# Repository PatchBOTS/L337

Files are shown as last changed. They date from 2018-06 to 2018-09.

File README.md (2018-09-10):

L337 (https://www.youtube.com/watch?v=H4KK212-Jss)
# L3-37 Voice Assistant
### Please Read Before Downloading 3D File

## Overview

## CODE
# Amazon Voice Services Code 
My friend @henrymendez is helping me with this section.  There may be a video tutorial down the line, but at the very least Henry will be writing a super awesome script to speed up the install process.  Check back. 

# Arduino Code
Very simple code. My goal is to eliminate the Arduino altogether, but for now this operates the servo and the neopixels. 

## 3D Files
The 3D files are free for download.  There will be some updates in the near future to a couple of the main parts.  If you see a "-CS" attached to any of the files, that means it is "changing soon,"  print those last. 

I'm happy to distribute these files for free but they are not guaranteed to work.  I am very big on the "print quick and dirty and fix later" philosophy, so there may be some physical editing to the parts needed which I did not document. 

## Changes coming in V2
### Physical
At the moment L3's head lists a little to the left. This is because of my 'smart' idea to only attach via the servo spline. I'm going to modify the top of the neck piece to add in a small axle to support the load.  Also, I'm going to expand the top of the neck piece to hold some of the components (of which there will hopefully be fewer of) to take some weight off the perimeter. 
### Electrical
There is a slight hum to the amplifier. I'm going to do more research on power de-coupling and ground loops to see if I can eliminate it. I have a feeling if I get rid of hte arduino circuit that will help.  Also, I'm hoping to be able to eliminate the SBEC which I'm sure isn't helping anything. 
### Components
As mentioned above I'm going to try to eliminate the arduino and circuit board all together. This will make the entire project less complicated and less noisy in the wires. 
I used a MEGA Scale Servo because I happened to have one on hand.  L3's head came in surprisingly light, so I think if I add in the axle to support more of the weight (which will also be moved off the head) I can use a much less powerful servo which doesn't require the SBEC.  
At the moment I'm using a cheap buck converter chip to step down the voltage. I'm going to upgrade this to a board with better voltage stability to hopefully help the amplifier hum. 
### Coding
I'm going to try to figure out more about coding the pinouts on the Pi.  If I can get two pinouts with one running a software PWM, I can eliminate the Arduino altogether.  I think this is the key to V2. 

<a href="https://www.buymeacoffee.com/WjRBDa3dZ" target="_blank">Buy Me A Coffee</a>

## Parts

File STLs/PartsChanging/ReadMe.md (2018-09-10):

These parts are from a now deprecated V1.  All these parts have either changed or are no longer necessary.   Use the V2 parts for all of these components.

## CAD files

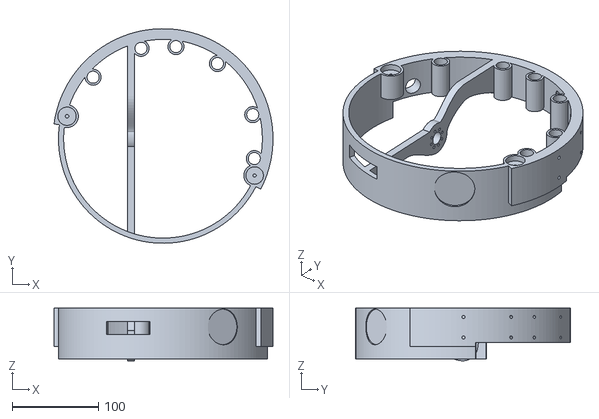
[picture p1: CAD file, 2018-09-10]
STLs/V2/HEAD_STRUCTURE_MainRing.STL
254.5 x 249.3 x 61.3

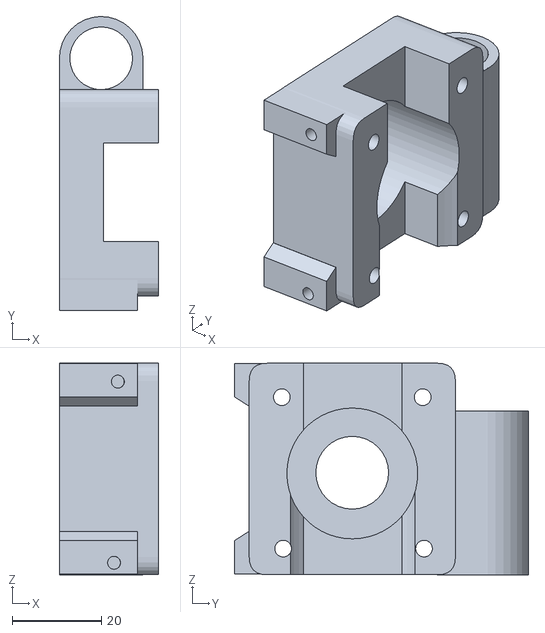
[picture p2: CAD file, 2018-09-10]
STLs/V2/HEAD_SERVOBLOCK_Main.STL
22.2 x 65.9 x 47.4

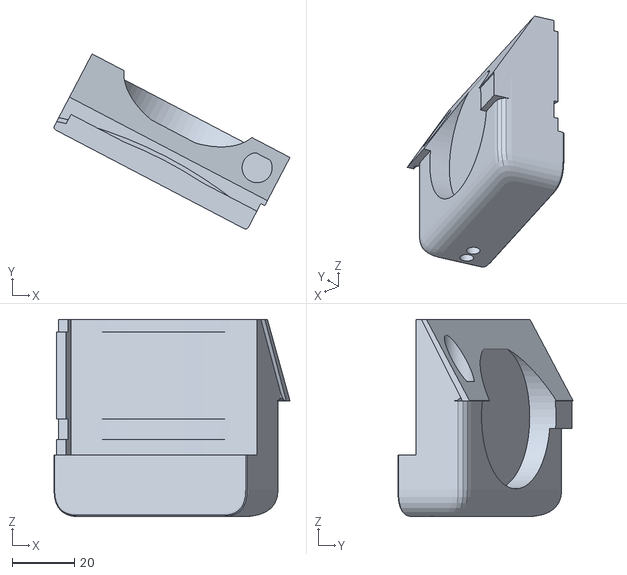
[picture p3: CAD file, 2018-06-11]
STLs/ANTENNA_Main.STL
75.9 x 56.4 x 63.5

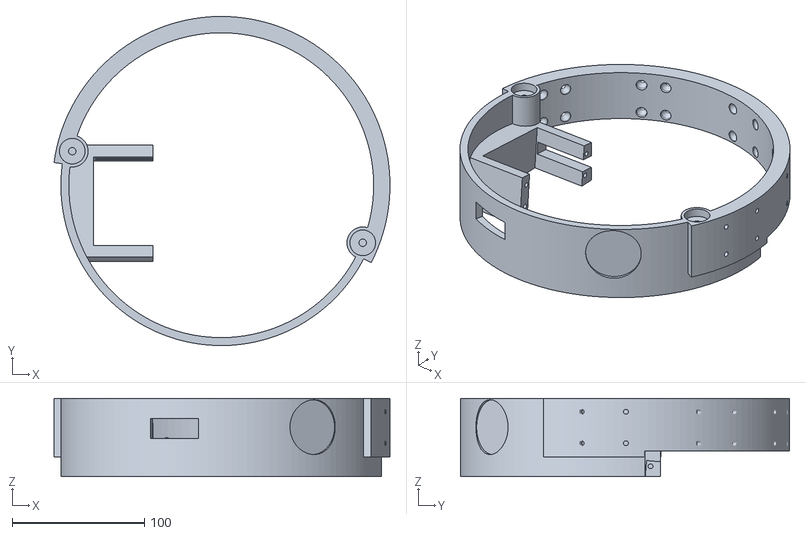
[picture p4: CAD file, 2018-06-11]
STLs/PartsChanging/HEAD_STRUCTURE_MainRing.STL
254.5 x 249.3 x 59.4

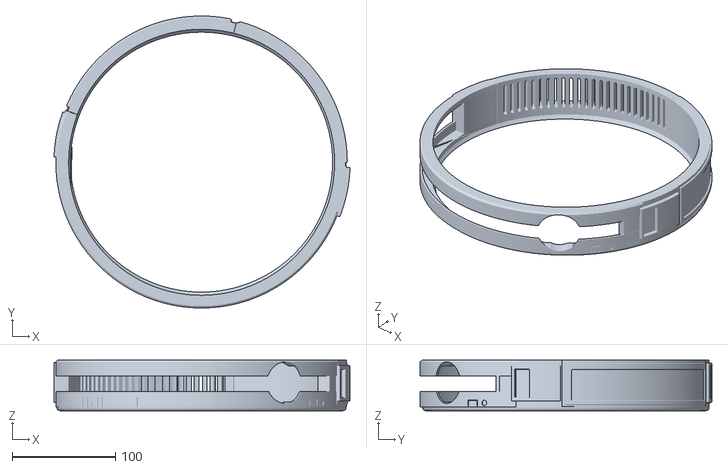
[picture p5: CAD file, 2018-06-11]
STLs/HEAD_AESTHETIC_Main.STL
287.1 x 283.2 x 49.1

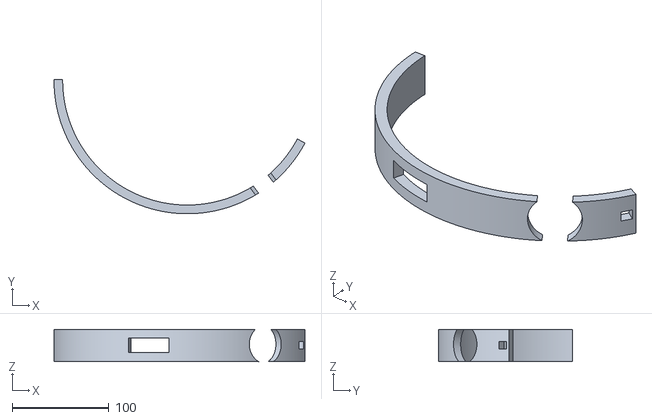
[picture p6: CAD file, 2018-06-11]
STLs/HEAD_STRUCTURE_VisorBand.STL
259.2 x 138.9 x 33.2

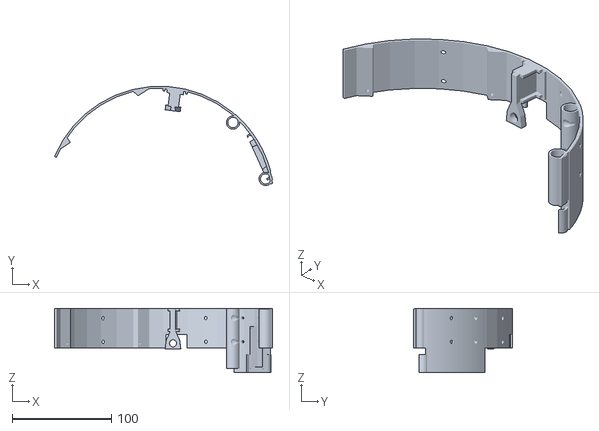
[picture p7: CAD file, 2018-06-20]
STLs/PartsChanging/HEAD_ELECTRICAL_Mount-CS.STL
219.6 x 99.8 x 64.8

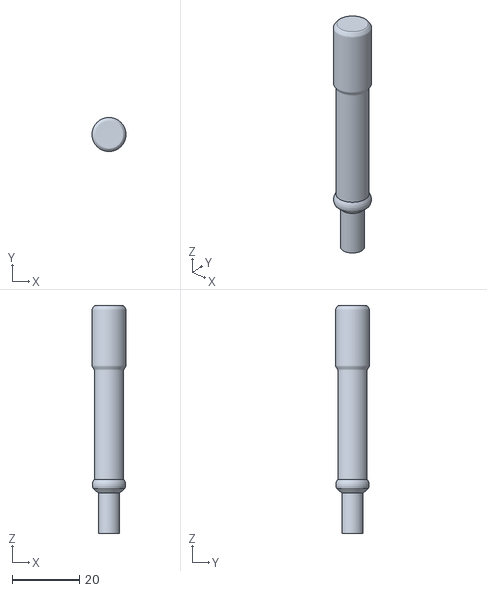
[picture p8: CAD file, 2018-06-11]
STLs/ANTENNA_Antenna.STL
10.1 x 10.1 x 68.0

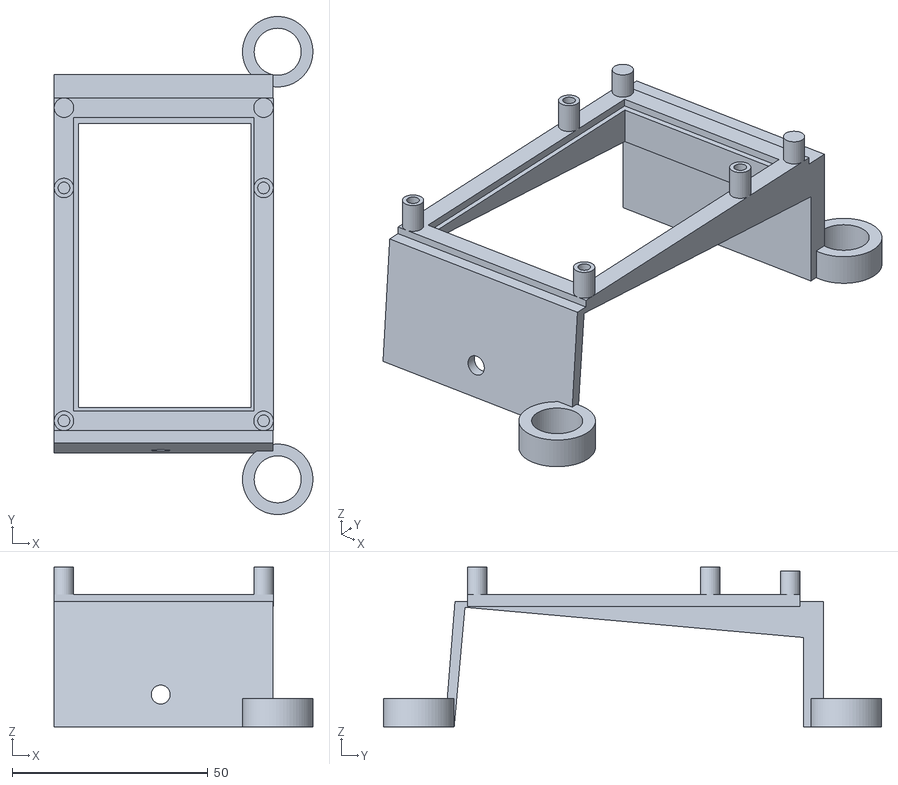
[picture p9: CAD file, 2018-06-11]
STLs/PartsChanging/HEAD_ELECTRICAL_PiHolder.STL
66.1 x 127.2 x 40.8

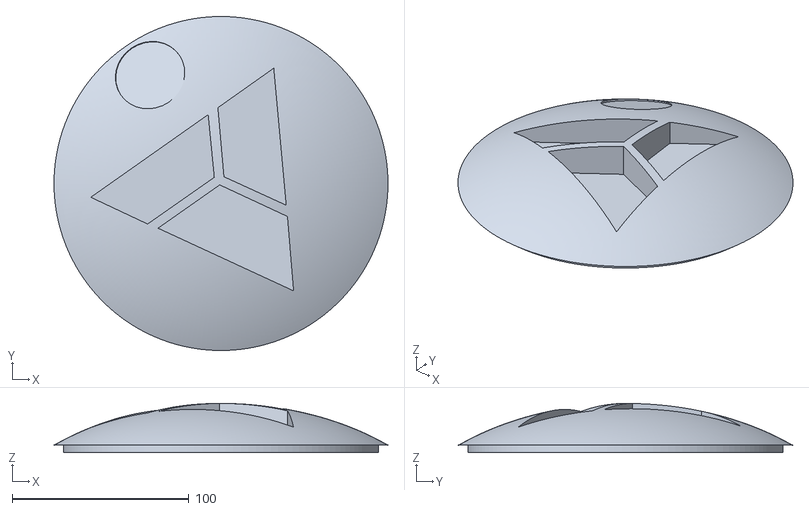
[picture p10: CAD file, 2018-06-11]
STLs/HEAD_LID_Cap.STL
189.1 x 189.1 x 27.8

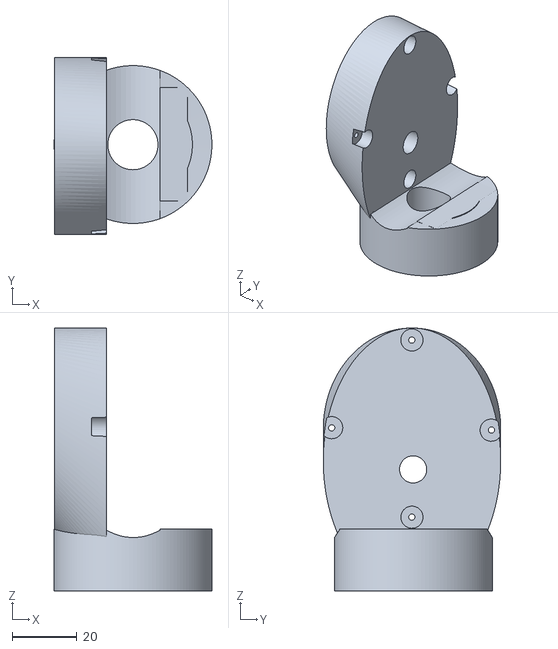
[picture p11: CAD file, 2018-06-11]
STLs/PartsChanging/BASE_NeckCap-CS.STL
48.8 x 54.9 x 81.4

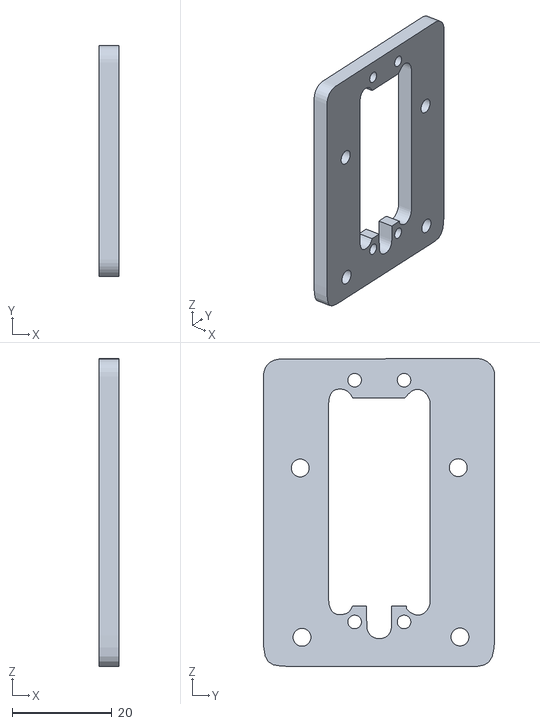
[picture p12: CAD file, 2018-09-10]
STLs/V2/HEAD_SERVOBLOCK_Plate.STL
4.00 x 46.3 x 61.6

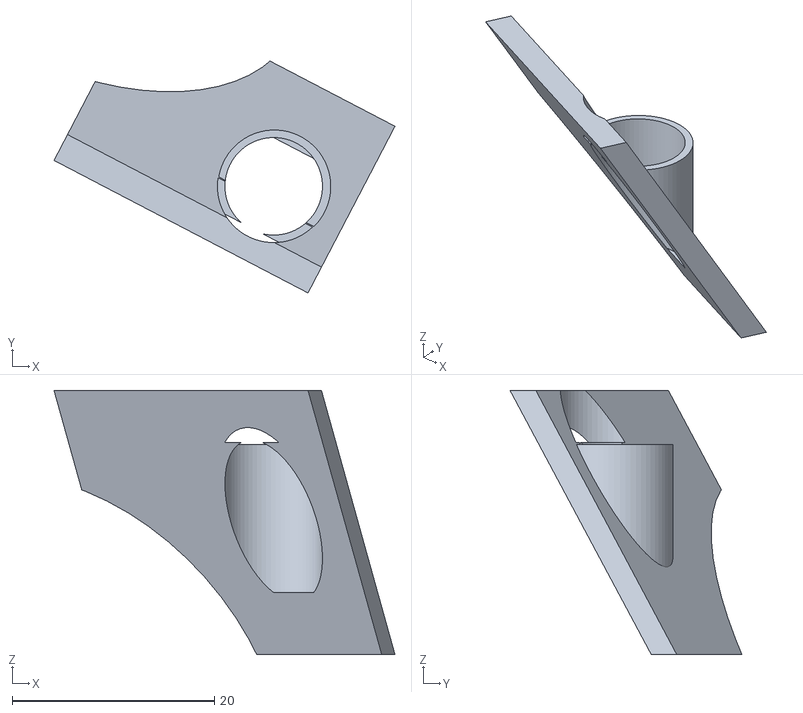
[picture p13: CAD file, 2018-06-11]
STLs/ANTENNA_SilverHolder.STL
33.8 x 23.0 x 26.1

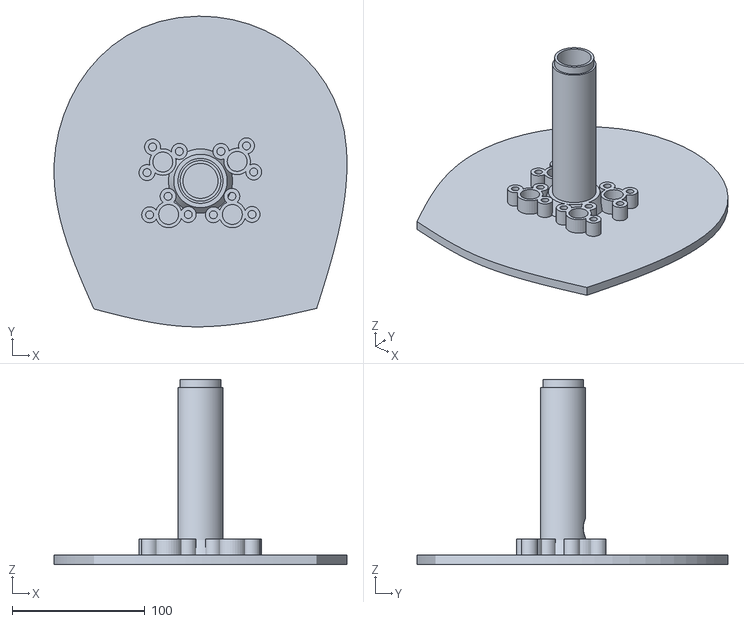
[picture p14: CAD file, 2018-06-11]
STLs/PartsChanging/BASE_BaseAndNeck-CS.STL
220.7 x 234.0 x 139.4

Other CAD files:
STLs/V2/BASE_BaseandNeck.STL
STLs/PartsChanging/HEAD_ELECTRICAL_MountCover.STL
STLs/V2/HEAD_ELECTRICAL_SpeakerMount.STL
STLs/HEAD_AESTHETIC_EarGreebly.STL
STLs/ANTENNA_Ring.STL
STLs/BASE_Collar.STL
STLs/BASE_CollarGreebly.STL
STLs/BASE_WireGrommit.STL
STLs/HEAD_AESTHETIC_Eye.STL
STLs/HEAD_AESTHETIC_EyeLid.STL
STLs/HEAD_AESTHETIC_MouthGreebly.STL
STLs/HEAD_AESTHETIC_VisorGreebly.STL
STLs/HEAD_ELECTRICAL_NeoDiffusex2.STL
STLs/HEAD_ELECTRICAL_NeoPixelHolder.STL
STLs/HEAD_LID_Base.STL
STLs/HEAD_LID_Cap_Holo.STL
STLs/HEAD_LID_Cap_T1.STL
STLs/HEAD_LID_Cap_T2.STL
STLs/HEAD_LID_Cap_T3.STL
STLs/PartsChanging/HEAD_ELECTRICAL_InternalHoop.STL
STLs/PartsChanging/HEAD_ELECTRICAL_SpeakerMount_CS.STL

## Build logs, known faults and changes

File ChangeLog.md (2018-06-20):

# Changelog
This file is to keep everyone following up to date on what is happening in between videos. 

## Alexa/Raspberry Pi Tutorial Video
This video is priority one.   @henrymendez put together a bunch of scripts to make this process super simple.  If you don't want to wait until the video comes out you can hop over to his git and follow those instructions. That will get you to where you need to be in no time flat! [Henry's Github](https://github.com/henrymendez/l3-37-alexa_patchbots) 

## File Updates
I created a new folder called "PartsChanging" in the STL folder.  These parts work as seen in the video, but I"m refining everything for V2 to make it work a little nicer.  Print them if you don't feel like waiting until V2, but V2 will be worth it. 

## [L3-37 Version 2]

## [2.0.0] - Coming Soon
### Definite Changes from V1
-Removing the Arduino Nano completely.  It's unecessary.  Looking into potentially using pigpio to control the servo. 
-Removing the Buck Converter and changing it to a better regulated power step down. The current buck is too noisy. 

### Possible Changes from V1
-Changing to a less powerful servo with a servo-block (half 3D printed, half aluminum) to make the head more level and save the SBEC Circuit. 
-Want to add a better amplification system.

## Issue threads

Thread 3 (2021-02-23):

./setup.sh: ERROR: make SampleApp -j2

atharv-kopparthi, 2021-02-23:
I'm runnig this on a raspberry pi 4 32 bit

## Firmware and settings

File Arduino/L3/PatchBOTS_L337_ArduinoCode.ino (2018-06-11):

// =======================================================================================
//                          L3-37 - AlexaPI Voice Assistant
// =======================================================================================
//                               Written By: PatchBOTS
// =======================================================================================
//
// ---------------------------------------------------------------------------------------
//                              ARUDINO NANO - PIN LAYOUT 
// ---------------------------------------------------------------------------------------
//
//                           +-----+
//              +------------| USB |------------+
//              |            +-----+            |
//              | [ ]D13                 D12[ ] |   
//              | [ ]3.3V                D11[ ]~|   
//              | [ ]V.ref     ___       D10[ ]~|   
//              | [ ]A0       / N \       D9[ ]~|  HS-805BB+ Servo (per TicoServo Library) 
//              | [ ]A1      /  A  \      D8[ ] |  
//              | [ ]A2      \  N  /      D7[ ] |  
//              | [ ]A3       \_0_/       D6[ ]~|  
//              | [ ]A4                   D5[ ]~|  
//              | [ ]A5                   D4[ ] |   
//              | [ ]A6                   D3[ ]~|  NeoPixels
//              | [ ]A7                   D2[ ] |  Input from Pi
//     5v In    | [ ]5V                  GND[ ] |     
//              | [ ]RST                 RST[ ] |  
//     GnD In   | [ ]GND   5V MOSI GND   TX1[ ] |   
//              | [ ]Vin   [ ] [ ] [ ]   RX1[ ] |   
//              |          [ ] [ ] [ ]          |
//              |          MISO SCK RST         |
//              | NANO-V3                       |
//              +-------------------------------+

// ---------------------------------------------------------------------------------------
//                                   NOTES
// --------------------------------------------------------------------------------------





// ---------------------------------------------------------------------------------------
//                         Libraries
// ---------------------------------------------------------------------------------------
#include <Adafruit_NeoPixel.h> 
#include <Adafruit_TiCoServo.h>

// ---------------------------------------------------------------------------------------
//                          Definitions Variables
// ---------------------------------------------------------------------------------------

 //********************Pinouts****************
#define PiRead_Pin     2 // Digital Pin Reading GPIO pin from RaspPi
#define NeoPixels      3 // Digital Write for 'always on' LED (see notes)
#define Servo_Pin      9 // Digital PWM Pin for Servo 


 //********************NEOPIXELS****************
#define NUMPIXELS      4
Adafruit_NeoPixel pixels = Adafruit_NeoPixel(NUMPIXELS, NeoPixels, NEO_GRB + NEO_KHZ800);


 //********************Servo****************
Adafruit_TiCoServo HeadServo;
//actual Min/Max of the HS-805BB+ is 556/2420. Head in down position will be at servo Max (endstop), and the Min will be the up position which will be tweaked. 
#define Servo_Min      2100 // tweak for up position (lower number-->higher head raise)
#define Servo_Max      2420 // Don't Touch. 


// ---------------------------------------------------------------------------------------
//                          Variables
// ---------------------------------------------------------------------------------------

int Trigger = 0; //varialbe attached to the read of the Servo_Pin


// =======================================================================================
//                          SETUP DEFINITIONS
// =======================================================================================

void setup() {

  //********************SETUP SERIAL****************
  Serial.begin(9600);

  //********************SETUP NEOPIXELS****************  
  pixels.begin(); // This initializes the NeoPixel library.
  pixels.show();

  //*********************PIN MODES******************

  pinMode(PiRead_Pin, INPUT);
  pinMode(NeoPixels, OUTPUT);
  pinMode(Servo_Pin, OUTPUT);


  //*********************Servo setup******************
  HeadServo.attach(Servo_Pin);
  HeadServo.write(Servo_Max);
  
}

// =======================================================================================
//                          MAIN APPLICATION LOOP
// =======================================================================================

void loop() {

//***************Read and Map*******************
// Get the updated trigger value :
  int Trigger = digitalRead(PiRead_Pin);

 
/* 
   //Debug to check this is working
 
   Serial.print("Trigger=");
   Serial.println(Trigger);
*/
   
  

  if ( Trigger == 1 ) {
      HeadServo.write(Servo_Min);
      pixels.setPixelColor(0, pixels.Color(255,255,255)); 
      pixels.setPixelColor(1, pixels.Color(255,255,255)); 
      pixels.setPixelColor(2, pixels.Color(255,255,255)); 
      pixels.setPixelColor(3, pixels.Color(255,255,255));
     } 
     else {
      pixels.setPixelColor(0, pixels.Color(0,0,0)); 
      pixels.setPixelColor(1, pixels.Color(0,0,0)); 
      pixels.setPixelColor(2, pixels.Color(0,0,0)); 
      pixels.setPixelColor(3, pixels.Color(0,0,0));
      HeadServo.write(Servo_Max);
  }
pixels.show();
}
